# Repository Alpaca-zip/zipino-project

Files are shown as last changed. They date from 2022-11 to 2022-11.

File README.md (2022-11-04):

# zipino rev1.0    
This is an Arduino compatible board equipped with the MPU6500 IMU sensor.  
  
 

## Bill of Materials:wrench:
- ATMEGA328P-AU
- FT232RL-REEL
- NCP1117ST50T3G
- LM358D
- FDN340P
- 1kΩ Chip Resistor (×4)
- 10kΩ Chip Resistor (×5)
- 47uF Aluminum Electrolytic Capacitors (×2)
- 100nF Multilayer Ceramic Capacitors (×9)
- 1uF Multilayer Ceramic Capacitors
- 10nF Multilayer Ceramic Capacitors
- White light Light Emitting Diodes
- Emerald light Light Emitting Diodes
- MF-MSMF050-2
- S2BA-13-F
- Surface Mount 5 Female Mini-B SMD USB Connectors
- DC-470-2.1GP
- CSTNE16M0V530000R0
- White Rectangle button Brick nogging SPST SMD Tactile Switches
- 1x2P Straight,P=2.54mm Pin Headers (×2)
- 1x8P Straight,P=2.54mm Female Headers (×2)
- 1x6P Straight,P=2.54mm Female Headers
- 1x10P Straight,P=2.54mm Female Headers
## How to Burn the Bootloader:fire:
The easiest way to burn the bootloader to zipino is using a second Arduino board as a programmer.
### 1. Connect the board
Connect the **PROGRAMMER BOARD** and **ZIPINO BOARD** as shown in the table below.
|  PROGRAMMER BOARD  |  ZIPINO BOARD  |
| :---: | :---: |
| 5V | 5V |
| GND | GND |
| D10 | RST |
| D11 | D11 |
| D12 | D12 |
| D13 | D13 |
### 2. Burn the bootloader from Arduino IDE.
  1. Open Arduino IDE.
  2. Connect the **PROGRAMMER BOARD** to the computer.
  3. Select your **PROGRAMMER BOARD** in *Tools > Board*, for example *Tools > Board > Arduino AVR Boards > Arduino Uno*.
  4. Select the port the board is connecting to in *Tools > Port*.
  5. Open *File > Examples > 11.ArduinoISP > ArduinoISP*.
  6. Click **Upload** button Upload to upload the sketch to the board.
  7. Select the **Arduino Uno** in *Tools > Board*.
  8. Select *Tools > Programmer > Arduino as ISP*.
  9. We can now start the burning process. To start the process, select *Tools > Burn Bootloader*.
  > [Arduino Help Center](https://support.arduino.cc/hc/en-us/articles/4841602539164-Burn-the-bootloader-on-UNO-Mega-and-classic-Nano-using-another-Arduino)

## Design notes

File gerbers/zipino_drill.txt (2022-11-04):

; NON-PLATED HOLES START AT T1
; THROUGH (PLATED) HOLES START AT T100
M48
INCH
T1C0.098425
T2C0.106299
T3C0.035433
T4C0.086614
T100C0.043307
T101C0.039370
T102C0.100000
T103C0.015748
%
T1
X012511Y017834
X018808Y017833
T2
X001384Y020669
X024227Y020662
X001375Y001371
X024216Y001374
T3
X019941Y001689
X021673Y001689
T4
X012449Y011598
X018746Y011596
T100
X020277Y021168
X015277Y020168
X010277Y021168
X018277Y020168
X021277Y020168
X006277Y020168
X005277Y020168
X004277Y021168
X008277Y020168
X003277Y020168
X013277Y020168
X015277Y021168
X019277Y020168
X020277Y020168
X003277Y021168
X013277Y021168
X014277Y021168
X012277Y021168
X008277Y021168
X011277Y020168
X012277Y020168
X006277Y021168
X016277Y020168
X014277Y020168
X009277Y021168
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

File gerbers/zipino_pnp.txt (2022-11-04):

*Pick And Place List
*Company=
*Author=
*eMail=
*
*Project=zipino
*Date=17:16:19
*CreatedBy=Fritzing 0.9.10b.2022-07-01.CD-2134-0-40d23c29
*
*
*Coordinates in mm, always center of component
*Origin 0/0=Lower left corner of PCB
*Rotation in degree (0-360, math. pos.)
*
*No;Value;Package;X;Y;Rotation;Side;Name
1;;;59.8424;-23.0688;0;Bottom;Copper Fill14
2;47ƒÊF;0605 [SMD, electrolytic];21.9379;-5.47989;0;Top;C12
3;;;23.7998;-34.8671;0;Bottom;Copper Fill3
4;;;3.63021;-18.9631;0;Bottom;TXT2
5;;;53.467;-24.0467;0;Bottom;Copper Fill7
6;;;31.623;-21.1257;0;Bottom;Copper Fill10
7;;;51.5004;-10.8504;0;Bottom;Via37
8;;;47.6159;-29.4546;0;Bottom;Hole7
9;;;20.5994;-37.5849;0;Bottom;Copper Fill44
10;;;25.8467;-36.5044;0;Bottom;Via33
11;;;4.65864;-43.3778;0;Bottom;TXT2
12;10k;0603 [SMD];27.2961;-22.9968;180;Top;R7
13;;;3.35137;-8.80223;0;Bottom;TXT2
14;;;44.6151;-2.25349;0;Bottom;Copper Fill91
15;;;28.348;-25.7753;0;Bottom;TXT3
16;100nF;0603 [SMD, multilayer];49.3204;-17.0347;180;Top;C7
17;;;11.0998;-48.2656;0;Bottom;Copper Fill82
18;;;11.3735;-25.0788;0;Bottom;Via58
19;;THT;6.569;-39.5525;0;Bottom;J3
20;;;46.9284;-10.5964;0;Bottom;Via80
21;;;34.2336;-22.0308;0;Bottom;Via98
22;;;4.06202;-33.2185;0;Bottom;TXT2
23;;;25.8467;-34.9804;0;Bottom;Via26
24;;;12.4206;-26.2565;0;Bottom;Copper Fill52
25;;ptc-1812;61.6656;-10.4992;90;Top;F1
26;;;11.0236;-39.0327;0;Bottom;Copper Fill42
27;;;18.8214;-43.0459;0;Bottom;Copper Fill39
28;;;43.6264;-23.1669;0;Bottom;Via8
29;;;39.3087;-14.6604;0;Bottom;Via1
30;;;57.5962;-26.8329;0;Bottom;TXT2
31;;;17.4371;-48.7228;0;Bottom;Copper Fill24
32;;;57.0936;-10.0928;0;Bottom;Via102
33;;ssop28db;41.6611;-15.5308;0;Top;U2
34;;;20.2692;-43.9603;0;Bottom;Copper Fill38
35;;;54.5536;-10.3468;0;Bottom;Via45
36;;;26.4922;-24.8849;0;Bottom;Copper Fill53
37;;;45.9176;-8.06078;0;Bottom;Via81
38;;;9.271;-18.1285;0;Bottom;Copper Fill62
39;;;17.4371;-48.7228;0;Bottom;Copper Fill86
40;;;23.3067;-32.6944;0;Bottom;Via17
41;;;57.5967;-29.3764;0;Bottom;TXT2
42;;;24.9112;-42.8723;0;Bottom;TXT7
43;;;22.5044;-16.3759;0;Bottom;Copper Fill55
44;;;46.9591;-20.0896;0;Bottom;Via40
45;;;22.225;-16.6299;0;Bottom;Copper Fill65
46;;;61.5381;-52.4833;0;Bottom;Hole2
47;;THT;54.8273;-21.7724;0;Bottom;J2
48;1k;0603 [SMD];22.9781;-20.4568;0;Top;R4
49;;;41.3404;-5.51641;0;Bottom;Via79
50;;;57.5959;-31.9208;0;Bottom;TXT2
51;100nF;0603 [SMD, multilayer];22.9002;-12.8368;180;Top;C4
52;;;27.5421;-28.2122;0;Bottom;TXT6
53;;;48.3616;-17.6967;0;Bottom;Copper Fill63
54;;;3.49489;-3.48429;0;Bottom;Hole3
55;;tactile-switch-1101ne;60.6496;-38.8968;-90;Top;S1
56;;;24.6071;-11.4535;0;Bottom;Via2
57;;;15.7988;-37.1785;0;Bottom;Copper Fill45
58;;;24.5816;-24.8994;0;Bottom;Via64
59;;;57.1568;-43.3749;0;Bottom;TXT2
60;;;22.4917;-3.25679;0;Bottom;Copper Fill29
61;100nF;0603 [SMD, multilayer];49.4113;-14.5722;0;Top;C3
62;30mA;0603 [SMD];27.2182;-20.4568;180;Top;LED1
63;;;9.84438;-8.81839;0;Bottom;Via15
64;;;18.4277;-48.7228;0;Bottom;Copper Fill87
65;;;57.1556;-48.4593;0;Bottom;TXT2
66;;;53.3654;-43.0459;0;Bottom;Copper Fill40
67;;;8.509;-22.0909;0;Bottom;Copper Fill57
68;;;53.5178;-16.8331;0;Bottom;Copper Fill9
69;;;9.0551;-37.0388;0;Bottom;Copper Fill81
70;;;21.4736;-38.7904;0;Bottom;Via28
71;;;20.5124;-13.6444;0;Bottom;Via77
72;;;12.6238;-6.19049;0;Bottom;Copper Fill33
73;;;21.5011;-3.25679;0;Bottom;Copper Fill28
74;;;19.5271;-23.1376;0;Bottom;Via59
75;100nF;0603 [SMD, multilayer];16.8042;-20.4568;0;Top;C1
76;;;20.7716;-30.0542;0;Bottom;Via54
77;;;47.7741;-45.296;0;Bottom;Hole5
78;;;57.5928;-21.7544;0;Bottom;TXT2
79;;;19.5271;-20.5976;0;Bottom;Via71
80;;;22.8036;-31.4288;0;Bottom;Via53
81;;THT;60.3956;-29.3968;0;Bottom;J6
82;;so08;40.8989;-7.10195;90;Top;U5
83;;;52.2675;-20.7608;0;Bottom;Via35
84;;;57.1503;-24.3057;0;Bottom;TXT2
85;;sot23-3;58.1756;-12.0908;180;Top;U6
86;;;22.4917;-3.25679;0;Bottom;Copper Fill90
87;;;28.5293;-26.8239;0;Bottom;TXT6
88;;;26.3398;-28.3901;0;Bottom;Copper Fill49
89;;;32.0802;-10.5593;0;Bottom;Copper Fill67
90;;;54.483;-28.0091;0;Bottom;Copper Fill11
91;;;10.5791;-48.7228;0;Bottom;Copper Fill83
92;;;52.5471;-15.7715;0;Bottom;Via44
93;;;38.8004;-16.9464;0;Bottom;Via22
94;;;27.5523;-25.9378;0;Bottom;TXT4
95;;;18.3642;-25.5707;0;Bottom;Copper Fill6
96;1ƒÊF;0603 [SMD, multilayer];49.3027;-19.7404;180;Top;C6
97;;;9.0551;-37.0388;0;Bottom;Copper Fill18
98;;;34.2336;-20.5068;0;Bottom;Via66
99;;;4.62562;-30.6602;0;Bottom;TXT2
100;;;51.7544;-19.4864;0;Bottom;Via34
101;;;36.2911;-7.89755;0;Bottom;Via74
102;10k;0603 [SMD];22.9781;-15.3768;0;Top;R2
103;100nF;0603 [SMD, multilayer];31.5227;-23.0424;180;Top;C11
104;;;60.3955;-23.0468;0;Bottom;Via92
105;;;44.1071;-1.73279;0;Bottom;Copper Fill93
106;;;10.5791;-48.7228;0;Bottom;Copper Fill21
107;;;20.8788;-28.5679;0;Bottom;Copper Fill50
108;;;58.4671;-19.2207;0;Bottom;TXT2
109;;;27.1216;-34.4768;0;Bottom;Via29
110;;;53.3654;-36.2133;0;Bottom;Copper Fill2
111;;;19.0191;-37.1076;0;Bottom;Via52
112;1k;0603 [SMD];22.9781;-22.9968;0;Top;R1
113;;;27.7548;-26.9092;-90;Bottom;TXT3
114;;;23.7626;-28.3903;0;Top;Pad1
115;adjustable;sot223;31.5821;-13.0908;-90;Top;U4
116;;;46.7614;-31.7683;0;Bottom;Copper Fill69
117;;;19.1516;-31.4889;0;Bottom;Copper Fill48
118;;;4.06738;-40.8358;0;Bottom;TXT2
119;;;60.833;-23.0688;0;Bottom;Copper Fill79
120;;;27.5497;-25.8288;0;Bottom;TXT5
121;;;8.6868;-42.1823;0;Bottom;Copper Fill41
122;;;17.9775;-48.7009;0;Bottom;Via85
123;;;17.9578;-48.2656;0;Bottom;Copper Fill23
124;;;22.0218;-3.77749;0;Bottom;Copper Fill26
125;;;57.1463;-40.8317;0;Bottom;TXT2
126;47ƒÊF;0605 [SMD, electrolytic];31.8439;-5.47989;0;Top;C13
127;;;61.5105;-3.49022;0;Bottom;Hole4
128;;;45.0977;-1.73279;0;Bottom;Copper Fill94
129;;;26.1056;-30.1588;0;Bottom;Via96
130;;;61.3918;-3.29489;0;Bottom;Copper Fill75
131;;;8.5344;-46.7289;0;Bottom;Copper Fill36
132;;;48.5394;-11.3721;0;Bottom;Copper Fill68
133;;;35.2444;-16.9464;0;Bottom;Via23
134;;;4.24066;-13.8922;0;Bottom;TXT2
135;;THT;60.3956;-47.1768;0;Bottom;J7
136;;;23.5966;-38.1437;0;Bottom;Copper Fill1
137;;;22.8291;-11.4536;0;Bottom;Via73
138;;;3.61525;-21.5036;0;Bottom;TXT2
139;;;29.5487;-25.8194;0;Bottom;TXT6
140;;;10.0457;-37.0388;0;Bottom;Copper Fill19
141;;;16.6624;-26.7899;0;Bottom;Copper Fill51
142;;;17.9681;-30.1466;0;Bottom;Via57
143;;;21.0256;-27.1108;0;Bottom;Via60
144;;;60.3631;-22.6243;0;Bottom;Copper Fill13
145;;;11.1195;-48.7009;0;Bottom;Via86
146;1k;0603 [SMD];49.3986;-9.66874;0;Top;R5
147;;;25.8467;-37.7744;0;Bottom;Via32
148;;;4.0654;-24.0415;0;Bottom;TXT2
149;;;9.5885;-37.5468;0;Bottom;Copper Fill16
150;;;46.9591;-21.3596;0;Bottom;Via38
151;;;11.5697;-48.7228;0;Bottom;Copper Fill84
152;;;44.6151;-1.31369;0;Bottom;Copper Fill30
153;;;21.4238;-25.1143;0;Bottom;Via70
154;100nF;0603 [SMD, multilayer];16.8042;-22.9968;0;Top;C2
155;;;31.6226;-29.4608;0;Bottom;Hole8
156;;;44.2468;-3.54889;0;Bottom;Copper Fill74
157;10k;0603 [SMD];16.8821;-28.0768;0;Top;R9
158;;;4.62788;-26.577;0;Bottom;TXT2
159;;;42.6411;-21.3596;0;Bottom;Via46
160;;;15.3416;-10.8641;0;Bottom;Copper Fill70
161;;;30.5308;-28.0091;0;Bottom;Copper Fill5
162;;;30.861;-41.4965;0;Bottom;Copper Fill37
163;;;3.80039;-11.3443;0;Bottom;TXT2
164;;;21.2852;-32.6319;0;Bottom;Copper Fill4
165;100nF;0603 [SMD, multilayer];31.6008;-20.5024;180;Top;C10
166;;;36.2911;-9.42155;0;Bottom;Via50
167;;;3.51691;-52.5008;0;Bottom;Hole1
168;10nF;0603 [SMD, multilayer];31.6008;-17.9624;0;Top;C9
169;;;40.8324;-8.31041;0;Bottom;Via78
170;;tqfp;19.6669;-37.0983;45;Top;U1
171;;;8.1026;-24.1483;0;Bottom;Copper Fill54
172;;QFN;23.767;-28.3553;0;Top;Part1
173;;;40.5384;-15.5377;0;Bottom;Copper Fill64
174;;;15.0876;-41.1155;0;Bottom;Copper Fill43
175;;;18.4277;-48.7228;0;Bottom;Copper Fill25
176;;;51.4214;-18.2164;0;Bottom;Via25
177;;;11.5697;-48.7228;0;Bottom;Copper Fill22
178;;;31.778;-45.2985;0;Bottom;Hole6
179;;;62.817;-27.8594;0;Bottom;TXT2
180;;;20.0044;-35.9417;0;Bottom;Via51
181;;;44.1071;-1.73279;0;Bottom;Copper Fill31
182;;;61.214;-6.26669;0;Bottom;Copper Fill73
183;;;31.9424;-3.23041;0;Bottom;Via75
184;;;26.0961;-15.4146;0;Bottom;Via9
185;;;25.4;-10.1021;0;Bottom;Copper Fill71
186;;;20.2692;-28.0091;0;Bottom;Copper Fill35
187;;;13.7818;-45.359;0;Bottom;IMG2
188;;;19.4921;-25.0666;0;Bottom;Via61
189;;;46.1664;-15.5841;0;Bottom;Via41
190;;;12.6238;-6.19049;0;Bottom;Copper Fill95
191;;;9.5885;-36.5816;0;Bottom;Copper Fill17
192;;;8.9154;-20.1351;0;Bottom;Copper Fill61
193;;;20.5124;-38.0284;0;Bottom;Via30
194;;;45.0977;-1.73279;0;Bottom;Copper Fill32
195;;;39.8018;-21.0241;0;Bottom;Copper Fill59
196;;THT;32.4558;-52.4986;-90;Bottom;J5
197;;;60.3631;-23.5895;0;Bottom;Copper Fill76
198;;;24.3;-47.1092;0;Bottom;IMG1
199;;resonator-smd;12.1443;-40.5228;-90;Top;Y1
200;;;41.337;-13.3858;0;Bottom;Via47
201;;;57.1506;-45.9139;0;Bottom;TXT2
202;;;60.3631;-23.5895;0;Bottom;Copper Fill12
203;;;26.1311;-13.7395;0;Bottom;Via3
204;;usb-minib;52.8516;-4.04077;-90;Top;X1
205;;;63.2017;-30.3898;0;Bottom;TXT2
206;;;60.3631;-22.6243;0;Bottom;Copper Fill77
207;;;33.147;-14.3185;0;Bottom;Copper Fill66
208;;;22.0218;-2.81229;0;Bottom;Copper Fill27
209;;;22.0415;-3.23479;0;Bottom;Via84
210;;;26.3144;-32.5049;0;Bottom;Copper Fill46
211;;;24.8304;-34.0424;0;Bottom;Via27
212;;;43.6571;-17.0415;0;Bottom;Via24
213;;;57.1551;-38.3016;0;Bottom;TXT2
214;;;4.075;-35.7656;0;Bottom;TXT2
215;1k;0603 [SMD];49.3986;-12.2087;0;Top;R6
216;;;60.833;-23.0688;0;Bottom;Copper Fill15
217;;;9.5885;-36.5816;0;Bottom;Copper Fill80
218;;;44.6151;-1.31369;0;Bottom;Copper Fill92
219;;;20.5124;-16.1844;0;Bottom;Via11
220;;;4.24151;-16.4271;0;Bottom;TXT2
221;;;24.5816;-32.6988;0;Bottom;Via97
222;30mA;0603 [SMD];27.2182;-17.9168;180;Top;LED2
223;;;44.6278;-21.0241;0;Bottom;Copper Fill60
224;;;3.1778;-45.9207;0;Bottom;TXT2
225;;;46.8122;-23.1323;0;Bottom;Copper Fill56
226;100nF;0603 [SMD, multilayer];40.8986;-2.25883;-1.59028e-15;Top;C5
227;;;4.64481;-38.2835;0;Bottom;TXT2
228;;;20.5124;-17.9624;0;Bottom;Via76
229;;;45.9176;-6.53678;0;Bottom;Via101
230;;THT;54.8273;-42.0925;0;Bottom;J1
231;;;60.3631;-31.6032;0;Bottom;Copper Fill34
232;10k;0603 [SMD];16.8821;-25.5368;0;Top;R8
233;;;11.0998;-48.2656;0;Bottom;Copper Fill20
234;;;3.18006;-48.4482;0;Bottom;TXT2
235;;;40.2245;-3.78284;0;Bottom;Via49
236;;;14.6756;-26.8568;0;Bottom;Via94
237;;;19.7504;-39.8611;0;Bottom;Via31
238;;;26.1056;-26.6028;0;Bottom;Via95
239;;;58.4682;-16.6788;0;Bottom;TXT2
240;;;24.3586;-21.2781;0;Bottom;Copper Fill8
241;;;9.59546;-37.0168;0;Bottom;Via87
242;10k;0603 [SMD];22.9781;-17.9168;0;Top;R3
243;;;33.9701;-17.9546;0;Bottom;Via65
244;;;8.5852;-33.1907;0;Bottom;Copper Fill47
245;;;61.6712;-10.5085;0;Bottom;Copper Fill72
246;;;21.5011;-3.25679;0;Bottom;Copper Fill89
247;;;44.6476;-1.71078;0;Bottom;Via82
248;;;13.7184;-8.08815;-90;Bottom;Power plug1
249;;THT;6.569;-15.1684;0;Bottom;J4
250;;;21.7932;-21.9131;0;Bottom;Copper Fill58
251;;sma-diode;15.7582;-17.4088;0;Top;D1
252;;;28.1631;-24.6616;0;Bottom;Via69
253;;;59.3796;-10.0928;0;Bottom;Via100
254;;;57.1568;-35.7587;0;Bottom;TXT2
255;;;59.8424;-23.0688;0;Bottom;Copper Fill78
256;;;17.9578;-48.2656;0;Bottom;Copper Fill85
257;;;23.3116;-24.8994;0;Bottom;Via62
258;;;52.0136;-9.58478;0;Bottom;Via36
259;100nF;0603 [SMD, multilayer];49.238;-22.2348;0;Top;C8
260;;;22.0218;-2.81229;0;Bottom;Copper Fill88

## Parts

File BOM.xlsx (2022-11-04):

Comment | Designator | Footprint | JLCPCB Part #（optional）
ATMEGA328P-AU | U1 | TQFP-32_7x7x08P | C14877
FT232RL-REEL | U2 | SSOP-28_208mil | C8690
MPU6500 | U3 | QFN-24 | C50278
NCP1117ST50T3G | U4 | SOT-223 | C17314
LM358D | U5 | SOIC-8 | C352856
FDN340P | U6 | SOT-23 | C347510
1K | R1,R2,R3,R4 | 0603 | C22548
10K | R5,R6,R7,R8,R9 | 0603 | C99198
47uF | C1,C2 | SMD,D6.3xL5.4mm | C2836440
100nF | C3,C4,C5,C6,C7,C8,C9,C10,C11 | 0603 | C14663
1uF | C12 | 0603 | C59302
10nF | C13 | 0603 | C100042
WHITE LIGHT | LED1 | 0603 | C84265
EMERALD LIGHT | LED2 | 0603 | C84267
MF-MSMF050-2 | F1 | 1812 | C17313
S2BA-13-F | D1 | SMA(DO-214AC) | C150463
MINI 5PTP | X1 | SMD | C2681563
DC-470-2.1GP | P1 | 插件 | C194407
CSTNE16M0V530000R0 | Y1 | SMD3213-3P | C341521
TS-1101-B-W | S1 | SMD | C500065
210-91-02GB01 | J1,J2 | 直插,P=2.54mm | C390678
C27438 | J3,J4 | 直插,P=2.54mm | C27438
C40877 | J5 | 直插,P=2.54mm | C40877
C35445 | J6 | 直插,P=2.55mm | C35445

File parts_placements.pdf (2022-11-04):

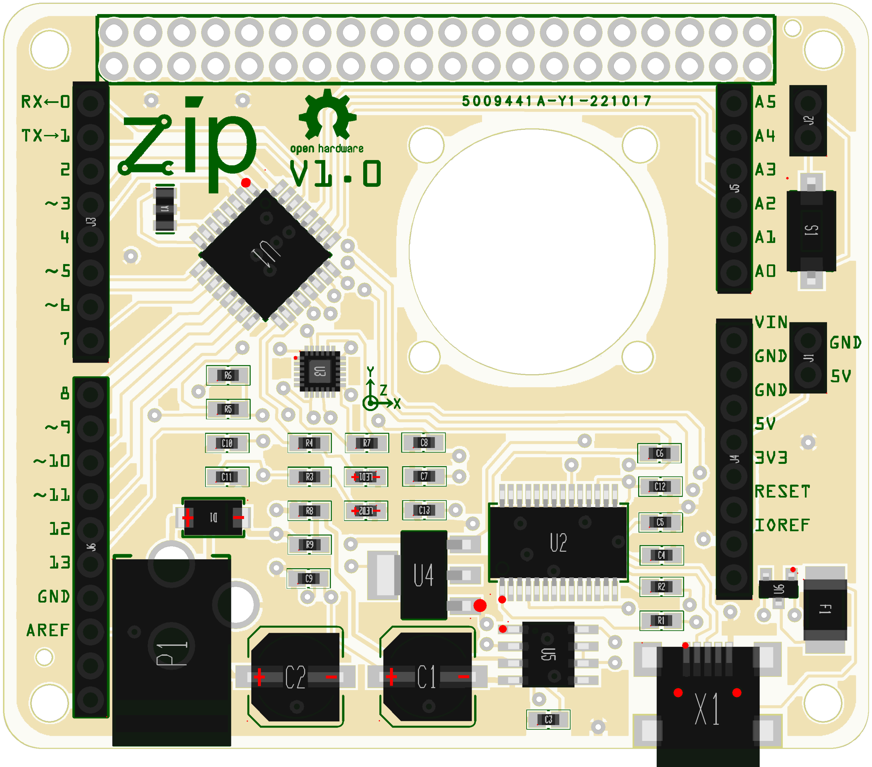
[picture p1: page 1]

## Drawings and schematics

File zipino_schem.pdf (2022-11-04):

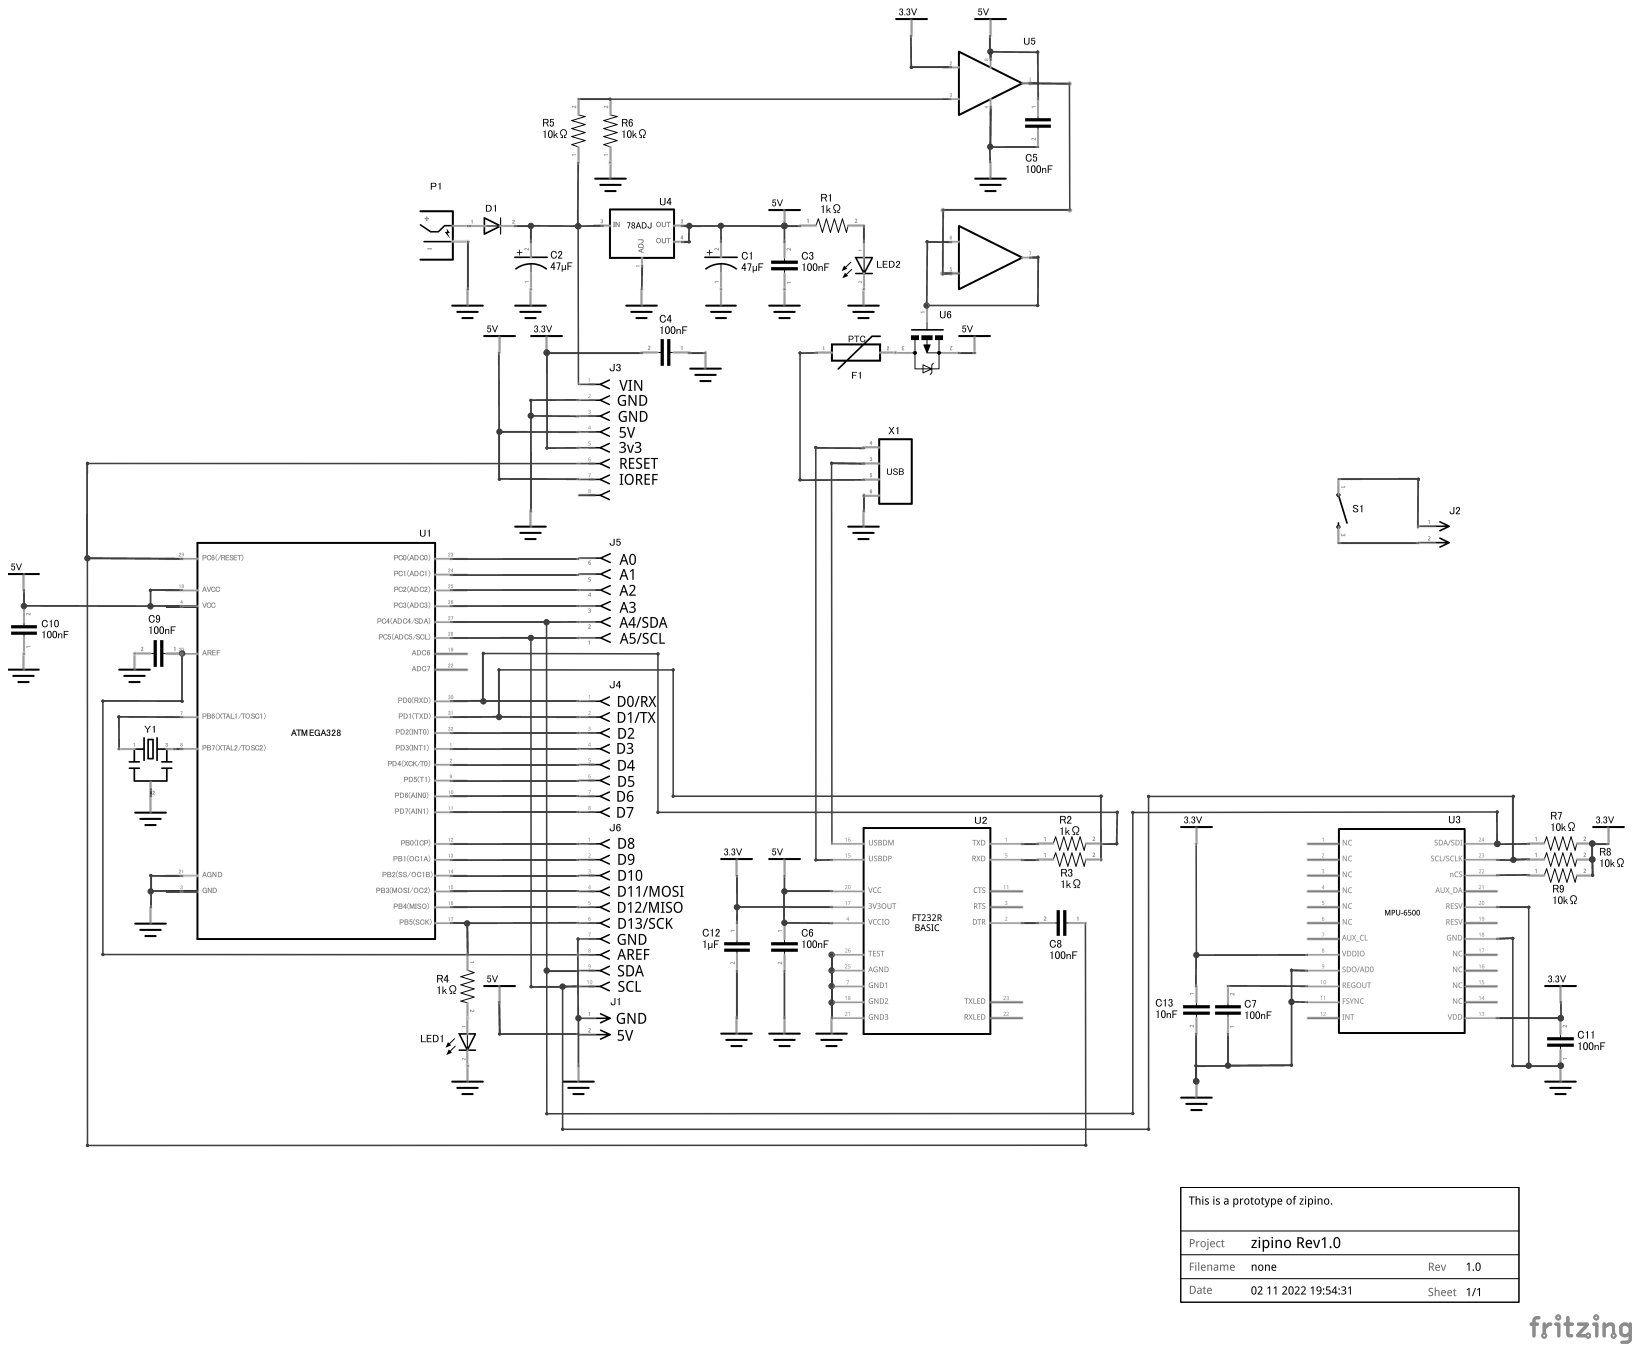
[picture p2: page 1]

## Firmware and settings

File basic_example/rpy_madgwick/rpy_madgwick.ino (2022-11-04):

/**
 * Copyright (C) 2022  Alpaca-zip
 *
 * Licensed under the Apache License, Version 2.0 (the "License");
 * you may not use this file except in compliance with the License.
 * You may obtain a copy of the License at
 *
 *     http://www.apache.org/licenses/LICENSE-2.0
 *
 * Unless required by applicable law or agreed to in writing, software
 * distributed under the License is distributed on an "AS IS" BASIS,
 * WITHOUT WARRANTIES OR CONDITIONS OF ANY KIND, either express or implied.
 * See the License for the specific language governing permissions and
 * limitations under the License.
 */
#include <Wire.h>
#include <MadgwickAHRS.h>
#define MPU6500_ADDR 0x68
Madgwick MadgwickFilter;
float gyro_offset[3] = {0.f, 0.f, 0.f};
float acc_offset[3] = {0.f, 0.f, 0.f};
float roll, pitch, yaw;
int gyro_range_index = 0;
int acc_range_index = 0;

float read_data(float gyro_raw[3], float gyro_data[3], float acc_raw[3], float acc_data[3]){
  uint8_t REG_GYRO_OUT = 0x43;
  uint8_t REG_ACC_OUT = 0x3B;
  uint8_t buf[6];
  Wire.beginTransmission(MPU6500_ADDR);
  Wire.write(REG_GYRO_OUT);
  Wire.endTransmission(false);
  Wire.requestFrom(MPU6500_ADDR, 6, true);
  if(Wire.available()){
    for(int i = 0; i < 6; i++){
      buf[i] = Wire.read();
    }
  }
  for(int i = 0; i < 3; i++){
    gyro_raw[i] = float(buf[2 * i] << 8 | buf[2 * i + 1]);
    gyro_data[i] = gyro_raw[i] - (gyro_offset[i] / (gyro_range_index + 1));
    gyro_data[i] *= ((gyro_range_index + 1) * 250.f /32768.0f);
  }
  Wire.beginTransmission(MPU6500_ADDR);
  Wire.write(REG_ACC_OUT);
  Wire.endTransmission(false);
  Wire.requestFrom(MPU6500_ADDR, 6, true);
  if(Wire.available()){
    for(int i = 0; i < 6; i++){
      buf[i] = Wire.read();
    }
  }
  for(int i = 0; i < 3; i++){
    acc_raw[i] = float(buf[2 * i] << 8 | buf[2 * i + 1]);
    acc_data[i] = acc_raw[i] - (acc_offset[i] / (acc_range_index + 1));
    acc_data[i] *= ((acc_range_index + 1)  /16384.0f);
  }
}

void reset_imu(){
  uint8_t REG_PWR_MGMT_1 = 0x6B;
  uint8_t RESET_VALUE = 0x80;
  Wire.beginTransmission(MPU6500_ADDR);
  Wire.write(REG_PWR_MGMT_1);
  Wire.write(RESET_VALUE);
  Wire.endTransmission(true);
  delay(10);
}

void calc_offset(float gyro_offset[3], float acc_offset[3]){
  float gyro_raw[3];
  float gyro_data[3];
  float acc_raw[3];
  float acc_data[3];
  float gyro_accumlator[3] = {0.f, 0.f, 0.f};
  float acc_accumlator[3] = {0.f, 0.f, 0.f};
  set_gyroRange(0);
  set_gyroLPF(6);
  set_accRange(0);
  set_accLPF(6);
  delay(100);
  for(int i = 0;i < 50;i++){
    read_data(gyro_raw, gyro_data, acc_raw, acc_data);
    for(int j = 0;j < 3;j++){
      gyro_accumlator[j] += gyro_raw[j];
      acc_accumlator[j] += acc_raw[j];
    }
    delay(1);
  }
  for(int i = 0; i < 3;i++){
    gyro_offset[i] = gyro_accumlator[i] / 50.f;
    acc_offset[i] = acc_accumlator[i] / 50.f;
    acc_offset[2] -= 16384.0f; 
  }
}

void set_gyroRange(int reg_index){
  uint8_t REG_GYRO_CONFIG = 0x1B;
  uint8_t reg[4] = {0x00, 0x08, 0x10, 0x18};
  /*
   * 0x00 => ±250dps
   * 0x08 => ±500dps
   * 0x10 => ±1000dps
   * 0x18 => ±2000dps
   */
  gyro_range_index = reg_index;
  Wire.beginTransmission(MPU6500_ADDR);
  Wire.write(REG_GYRO_CONFIG);
  Wire.write(reg[reg_index]);
  Wire.endTransmission(true);
  delay(10);
}

void set_accRange(int reg_index){
  uint8_t REG_ACC_CONFIG = 0x1C;
  uint8_t reg[4] = {0x00, 0x08, 0x10, 0x18};
  /*
   * 0x00 => ±2g
   * 0x08 => ±4g
   * 0x10 => ±8g
   * 0x18 => ±16g
   */
  acc_range_index = reg_index;
  Wire.beginTransmission(MPU6500_ADDR);
  Wire.write(REG_ACC_CONFIG);
  Wire.write(reg[reg_index]);
  Wire.endTransmission(true);
  delay(10);
}

void set_gyroLPF(int reg_index){
  uint8_t REG_CONFIG = 0x1A;
  uint8_t reg[7] = {0x00, 0x01, 0x02, 0x03, 0x04, 0x05, 0x06};
  /*
   * 0x00 => Bandwidth : 250(Hz) Delay : 0.97(ms)
   * 0x01 => Bandwidth : 184(Hz) Delay : 2.9(ms)
   * 0x02 => Bandwidth : 92(Hz) Delay : 3.9(ms)
   * 0x03 => Bandwidth : 41(Hz) Delay : 5.9(ms)
   * 0x04 => Bandwidth : 20(Hz) Delay : 9.9(ms)
   * 0x05 => Bandwidth : 10(Hz) Delay : 17.85(ms)
   * 0x06 => Bandwidth : 5(Hz) Delay : 33.48(ms)
   */
  Wire.beginTransmission(MPU6500_ADDR);
  Wire.write(REG_CONFIG);
  Wire.write(reg[reg_index]);
  Wire.endTransmission(true);
  delay(10);
}

void set_accLPF(int reg_index){
  uint8_t ACC_CONFIG = 0x1D;
  uint8_t reg[7] = {0x00, 0x01, 0x02, 0x03, 0x04, 0x05, 0x06};
  /*
   * 0x00 => Bandwidth : 460(Hz) Delay : 1.94(ms)
   * 0x01 => Bandwidth : 184(Hz) Delay : 5.8(ms)
   * 0x02 => Bandwidth : 92(Hz) Delay : 7.8(ms)
   * 0x03 => Bandwidth : 41(Hz) Delay : 11.8(ms)
   * 0x04 => Bandwidth : 20(Hz) Delay : 19.8(ms)
   * 0x05 => Bandwidth : 10(Hz) Delay : 35.7(ms)
   * 0x06 => Bandwidth : 5(Hz) Delay : 66.96(ms)
   */
  Wire.beginTransmission(MPU6500_ADDR);
  Wire.write(ACC_CONFIG);
  Wire.write(reg[reg_index]);
  Wire.endTransmission(true);
  delay(10);
}

void set_smplrtDiv(uint8_t samplrt_div){
  uint8_t REG_SAMPLRT_DIV = 0x19;
  /*
   * SAMPLE_RATE = INTERNAL_SAMPLE_RATE / (1 + samplrt_div)
   * where INTERNAL_SAMPLE_RATE = 1(kHz)
   * SAMPLRT_DIV is a number 0...255
   */
  Wire.beginTransmission(MPU6500_ADDR);
  Wire.write(REG_SAMPLRT_DIV);
  Wire.write(samplrt_div);
  Wire.endTransmission(true);
  delay(10);
}

void setup(){
  Serial.begin(115200);
  MadgwickFilter.begin(100);
  Wire.begin();
  reset_imu();
  delay(1000);
  calc_offset(gyro_offset, acc_offset);
  set_gyroRange(0);
  set_gyroLPF(6);
  set_accRange(0);
  set_accLPF(6);
  set_smplrtDiv(5);
}
 
void loop(){
  float timer = millis();
  float timeStep = 0.01;
  float gyro_raw[3];
  float gyro_data[3];
  float acc_raw[3];
  float acc_data[3];
  read_data(gyro_raw, gyro_data, acc_raw, acc_data);
  MadgwickFilter.updateIMU(gyro_data[0], gyro_data[1], gyro_data[2], acc_data[0], acc_data[1], acc_data[2]);
  roll = MadgwickFilter.getRoll();
  pitch = MadgwickFilter.getPitch();
  yaw  = MadgwickFilter.getYaw();
  Serial.println("%%%%%%%%%%%%%%%Roll Pitch Yaw data with Madgwick filter%%%%%%%%%%%%%%%");
  Serial.print("Roll: ");
  Serial.print(roll);
  Serial.println("°");
  Serial.print("Pitch: ");
  Serial.print(pitch);
  Serial.println("°");
  Serial.print("Yaw: ");
  Serial.print(yaw);
  Serial.println("°");
  delay((timeStep * 1000) - (millis() - timer));
}
